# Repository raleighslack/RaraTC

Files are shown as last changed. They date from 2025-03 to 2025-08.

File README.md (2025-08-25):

# RSync Firmware  
The goal of this project is to create a system of devices that are able to wirelessly sync to each other and output SMPTE LTC Timecode to make editing effortless.

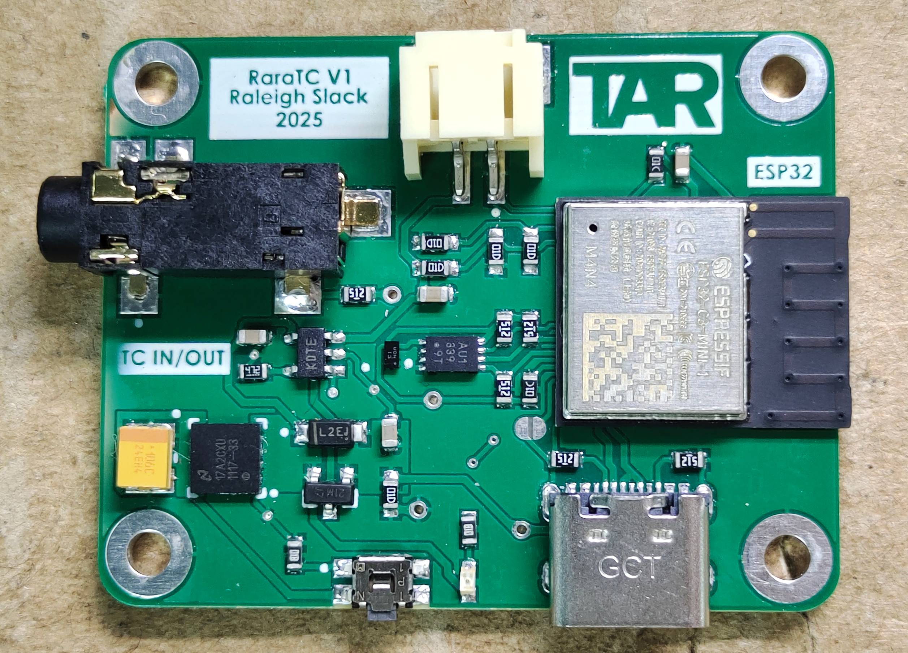
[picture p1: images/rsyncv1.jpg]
image info


## How to Use Example

### Hardware Required

The custom RSYNC board created by Raleigh Slack.  

### References used

[LTC Timecode Standard](https://law.resource.org/pub/in/bis/S04/is.12429.1.1988.pdf) - Describes the way in which LTC Timecode functions and gives specifications as how to meet the SMPTE standard.  
[USB-C in Embedded Designs: Practical Overview](https://fraimichael.medium.com/usb-c-in-embedded-designs-practical-overview-17bed72da05a) - A very good overview on how to incoporate USB-C into even the smallest designs.  
[ESP32-C3 Docs](https://docs.espressif.com/projects/esp-idf/en/v5.5/esp32c3/index.html) - Gives a great overview on how to use FreeRTOS, as well as ESP32 specific libraries.  

### Tools Used

[Altium Designer](https://www.altium.com/altium-designer) - Main PCB design software  
[EasyEDA](https://easyeda.com/) - Can generate footprints and symbols for Altium

### Build and Flash

Run `idf.py -p PORT flash monitor` to build, flash and monitor the project.

(To exit the serial monitor, type ``Ctrl-]``.)

See the [Getting Started Guide](https://docs.espressif.com/projects/esp-idf/en/latest/get-started/index.html) for full steps to configure and use ESP-IDF to build projects.

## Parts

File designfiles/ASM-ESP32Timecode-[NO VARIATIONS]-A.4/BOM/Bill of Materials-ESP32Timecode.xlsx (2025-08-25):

Line # | Name | Description | Designator | Revision ID | Revision Status | Quantity | Manufacturer 1 | Manufacturer Part Number 1 | Manufacturer Lifecycle 1 | Supplier 1 | Supplier Part Number 1 | Supplier Unit Price 1 | Supplier Subtotal 1
 | TAJB106M016RNJ | Tantalum Capacitor, 10 uF, +/- 20%, 16 V, -55 to 125 degC, 1411 (3528 Metric), RoHS, Tape and Reel | C1 | CMP-001-00050-7 | Up to date | 1 | Kyocera AVX | TAJB106M016RNJ | Volume Production | Future Electronics | 1399823 | 0.38 | 0.38
 | Capacitor 10µF +/-20% 10V 0603 | Chip Capacitor, 10µF +/-20%, 10V, 0603, Thickness 1 mm | C2, C3, C4, C5 | CMP-001-00075-4 | Up to date | 4 | Samsung | CL10A106KP8NNNC | Volume Production | Newark | 82AC9283 | 0.027 | 0.108
 | MBR120ESFT1G |  | D1 | CMP-1055-00434-2 | Up to date | 1 | ON Semiconductor | MBR120ESFT1G | Volume Production | Newark | 58M8776 | 0.134 | 0.134
 | VLMO1300-GS08 | VLMO1300-GS08 LED Uni-Color Soft Orange 611nm 2-Pin Chip 0603(1608Metric) T/R | D2 | CMP-00030-21709200-1 | Up to date | 1 | Vishay Semiconductors | VLMO1300-GS08 | Volume Production | Digikey | VLMO1300-GS08CT-ND | 0.22 | 0.22
 | USB4105-GF-A | CONN RCPT USB2.0 TYPEC 5A | J1 | CMP-245163-000001-1 | Up to date | 1 | Global Connector Technology | USB4105-GF-A | Unknown | Mouser | 640-USB4105-GF-A | 0.74 | 0.74
 | SJ2-35853B-SMT-TR | Connector | J2, J3 |  |  | 2
 | ESP32-C3-MINI-1-N4 | Multiprotocol Modules SMD module, ESP32-C3FN4, PCB antenna, -40 C +85 C | MD1 | CMP-10700-116589975-1 | Up to date | 1 | Espressif Systems | ESP32-C3-MINI-1-N4 | Unknown | Mouser | 356-ESP32-C3-MINI1N4 | 1.8 | 1.8
 | S2B-PH-K-S(LF)(SN) | Male Header, Pitch 2 mm, 1 x 2 Position, Height 4.8 mm, Tail Length 3.4 mm, -25 to 85 degC, RoHS, Bulk | P1 | CMP-1755-00004-1 | Up to date | 1 | JST | S2B-PH-K-S(LF)(SN) | Volume Production | Newark | 38K8066 | 0.037 | 0.037
 | DMG2301L-7 | MOSFET P-CH 20V 3A SOT23 | Q1 | CMP-12801-000065-1 | Up to date | 1 | Diodes | DMG2301L-7 | Volume Production | Digikey | DMG2301L-7DICT-ND | 0.23 | 0.23
 | AC0603FR-07100KL | RES 100KΩ 1.00% 0.1W 0603 | R1, R4, R5, R13, R14 | CMP-2000-04816-3 | Up to date | 5 | Yageo | AC0603FR-07100KL | Volume Production | Digikey | 311-100KLDCT-ND | 0.013 | 0.13
 | CRCW04021K00FKED | RES Thick Film, 1kΩ, 1%, 0.063W, 100ppm/°C, 0402 | R2, R8 | CMP-2002-08276-2 | Up to date | 2 | Vishay Dale | CRCW04021K00FKED | Volume Production | Avnet | 61M5261 | 0.012 | 0.12
 | CRCW04024K70FKED | RES Thick Film, 4.7kΩ, 1%, 0.063W, 100ppm/°C, 0402 | R3 | CMP-2002-00051-3 | Up to date | 1 | Vishay Dale | CRCW04024K70FKED | Unknown
 | CRCW06035K10FKEA | RES Thick Film, 5.1kΩ, 1%, 0.1W, 100ppm/°C, 0603 | R6, R7, R9, R10, R11, R12 | CMP-1012-00590-3 | Up to date | 6 | Bourns | CR0603-FX-5101ELF | Volume Production | Newark | 33AK8378 | 0.002 | 0.012
 | PTH-M2D5X5 | M2 PTH (2.5mm), 5mm pad | ST1, ST2, ST3, ST4 | CMP-00028-00004-2 | Up to date | 4
 | LM1117LD-3.3/NOPB | 800mA Low-Dropout Linear Regulator, 8-pin LLP, Pb-Free | U1 | CMP-0062-01399-3 | Up to date | 1 | TI National Semiconductor | LM1117LD-3.3/NOPB | Volume Production | Mouser | 926-LM1117LD33NOPB | 1.22 | 1.22
 | MCP7940MT-I/MNY | Low-Cost I2C™ Real-Time Clock / Calendar with SRAM, 400 KHz Communications Speed, 64 Bytes SRAM, -40 to 85 degC, 8-pin TDFN (MNY8), Tape and Reel | U2 | CMP-0186-00324-1 | Up to date | 1 | Microchip | MCP7940MT-I/MNY | Volume Production | Digikey | MCP7940MT-I/MNYCT-ND | 0.77 | 0.77
 | MCP73831T-2ACI/OT | IC CONTROLLR LI-ION 4.2V SOT23-5 | U3 | CMP-0133-00143-2 | Up to date | 1 | Microchip | MCP73831T-2ACI/OT | Volume Production | Farnell | 1332158 | 0.73832 | 0.73832
 | SIT1552AI-JF-DCC-32.768D | MEMS OSC TCXO 32.7680KHZ LVCMOS | Y1 | CMP-25159-262229-1 | Up to date | 1 | SiTime | SIT1552AI-JF-DCC-32.768D | Volume Production | Mouser | 788-1552AIJFDCC32.7D | 1.66 | 1.66

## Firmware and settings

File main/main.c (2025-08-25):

#include "freertos/FreeRTOS.h"
#include "freertos/task.h"
#include "esp_mac.h"
#include "esp_log.h"
#include "esp_timer.h"
#include "esp_wifi.h"
#include "esp_netif.h"
#include "esp_now.h"
#include "hal/cpu_hal.h"
#include "driver/gpio.h"
#include "smpte_timecode.h"
#include "communication.h"
#include "mcp7940.h"
#include "lipo.h"
#include "time.h"
#include "esp_sleep.h"
#include "nvs.h"
#include "mbedtls/base64.h"

#define USB_WAKE            0
#define LIPO_VOLTAGE        1
#define BTN_INPUT_PIN       3
#define LTC_OUTPUT_PIN      4
#define RTC_INPUT_PIN       5
#define LTC_FRAMERATE       24
#define LTC_BITS_PER_FRAME  80
#define CLOCK_TICKS_PER_SEC 160000000

#define GPIO_OUTPUT_PIN_SEL ((1ULL<<LTC_OUTPUT_PIN) | (1ULL<<LTC_OUTPUT_PIN))
#define GPIO_INPUT_RTC_PIN_SEL  ((1ULL<<RTC_INPUT_PIN) | (1ULL<<RTC_INPUT_PIN))
#define GPIO_INPUT_BTN_PIN_SEL  ((1ULL<<BTN_INPUT_PIN) | (1ULL<<BTN_INPUT_PIN))

static const char *TAG = "main";
static QueueHandle_t rtc_evt_queue;
static QueueHandle_t btn_evt_queue;

const float period_us = (((float)1/LTC_FRAMERATE)/LTC_BITS_PER_FRAME)*1000000;
const int64_t half_period_us = period_us/2.0;
const float frame_period_us = ((float)1/LTC_FRAMERATE) * 1000000;

volatile int frameOffset = 0;
volatile float timeOffsetMs = 1;
simple_frame current_simple_frame;
ltc_frame current_frame;
uint8_t current_bits[10];
esp_timer_handle_t periodic_timecode;
bool state = true;
volatile int bit_index = 0;                                                             //value from 0-79, the current transmitting bit
volatile int bit_local_counter = 0;                                                     //value either 0 or 1, either first half of period or 2nd half
static const char* BASE58_ALPHABET = "123456789ABCDEFGHJKLMNPQRSTUVWXYZabcdefghijkmnopqrstuvwxyz";

bool get_bit(uint8_t value, uint8_t index) {
    if (index > 7) return false;                                                        // Ensure index is within bounds
    return (value >> index) & 1;
}

static void lipo_task(void* arg) {
    while(1) {
        // float voltage = get_lipo_voltage();
        // ESP_LOGI(TAG, "VOLTAGE: %f", voltage);
        
        vTaskDelay(10000 / portTICK_PERIOD_MS);
    }
}

static void btn_task(void* arg) {
    int gpio_num;
    uint64_t prev_time = 0;
    bool is_down = false;
    while(1) {
        if (xQueueReceive(btn_evt_queue, &gpio_num, portMAX_DELAY)) {
            uint64_t current_time = esp_timer_get_time();
            uint64_t time_difference = current_time - prev_time;
            if (time_difference > 50000) {
                is_down = !is_down;
                float diff_helps = (float)(time_difference/1000000.0);
                ESP_LOGI(TAG, "BTN ISR, DIFFERENCE: %f, ISDOWN?: %d", diff_helps, is_down);
                prev_time = current_time;
                if((time_difference >= 5000000) && !is_down) {
                    ESP_ERROR_CHECK(ble_deinit());
                    vTaskDelete(xTaskGetHandle("lipo_task"));
                    esp_deep_sleep_start();
                }
            }
        }
    }
}

static void rtc_task(void* arg) {
    int gpio_num;
    while (1) {
        if (xQueueReceive(rtc_evt_queue, &gpio_num, portMAX_DELAY)) {
            if(gpio_num == RTC_INPUT_PIN) {
                uint64_t start = cpu_hal_get_cycle_count();
                uint8_t hours = get_rtc_hours();
                uint8_t minutes = get_rtc_minutes();
                uint8_t seconds = get_rtc_seconds();
                uint8_t days = get_rtc_date();

                int delayTime = (timeOffsetMs - ((cpu_hal_get_cycle_count() - start)/CLOCK_TICKS_PER_SEC) * 1000) / portTICK_PERIOD_MS;
                if(delayTime <0) {
                    delayTime=0;
                }

                vTaskDelay(delayTime);
                if (esp_timer_is_active(periodic_timecode)) {
                    ESP_ERROR_CHECK(esp_timer_stop(periodic_timecode));
                }

                current_simple_frame.frame = 0 + (frameOffset % LTC_FRAMERATE);
                current_simple_frame.second = seconds + (frameOffset / LTC_FRAMERATE);
                current_simple_frame.minute = minutes;
                current_simple_frame.hour = hours;

                if(current_simple_frame.second >= 60) {
                    current_simple_frame.minute += (current_simple_frame.second / 60);
                    current_simple_frame.second -= (60 - (current_simple_frame.second % 60));
                }

                // ESP_LOGI(TAG, "DAY: %d, TC ISR: %d:%d:%d:%d", days, current_simple_frame.hour, current_simple_frame.minute, current_simple_frame.second, current_simple_frame.frame);
        
                ESP_ERROR_CHECK(esp_timer_start_periodic(periodic_timecode, half_period_us));
            }
        }
    }
}

static void rtc_isr_handler(void* arg)
{
    int gpio_num = (int) arg;
    xQueueSendFromISR(rtc_evt_queue, &gpio_num, NULL);
}

static void btn_isr_handler(void* arg) {
    int gpio_num = (int) arg;
    xQueueSendFromISR(btn_evt_queue, &gpio_num, NULL);
}

void print_binary(uint8_t bits[10]) {
    for (int i = 0; i < 10; i++) {
        for (int j = 7; j >= 0; j--) {
            printf("%d", (bits[i] >> j) & 1);
        }
        printf(" ");
    }
    printf("\n");
}

void IRAM_ATTR periodic_timecode_callback(void* arg)
{
    bool bit = get_bit(reverse_bits(current_bits[(bit_index / 8)]), bit_index % 8);     //finally, a use for the modulo
    if(bit_local_counter == 0) {
        state = !state;
    }
    if(bit_local_counter == 1 && bit) {
        state = !state;
    }
    gpio_set_level(LTC_OUTPUT_PIN, state);
    bit_local_counter++;
    if(bit_local_counter >1) {
        bit_local_counter = 0;
        bit_index++;
    }
    if(bit_index > 79) {
        bit_index = 0;
        current_simple_frame.frame++;
        if(current_simple_frame.frame >= LTC_FRAMERATE) {
            current_simple_frame.frame = 0;
            current_simple_frame.second++;
            if(current_simple_frame.second >= 60) {
                current_simple_frame.second = 0;
                current_simple_frame.minute++;
                if(current_simple_frame.minute >= 60) {
                    current_simple_frame.minute = 0;
                    current_simple_frame.hour++;
                }
            }
        }
        create_frame_from_timecode(&current_frame, current_simple_frame.frame, current_simple_frame.second, current_simple_frame.minute, current_simple_frame.hour);
        create_bits_from_frame(current_bits, current_frame, LTC_FRAMERATE);
        // ESP_LOGI(TAG, "TC: %d:%d:%d:%d", current_simple_frame.hour, current_simple_frame.minute, current_simple_frame.second, current_simple_frame.frame);
        // log_frame_from_bits(current_bits);
        // print_binary(current_bits);
    }
}

void encode_base58(uint64_t value, char *output, size_t output_size) {
    char buffer[16]; // max 11 chars for 64-bit + null
    int i = 0;

    do {
        buffer[i++] = BASE58_ALPHABET[value % 58];
        value /= 58;
    } while (value && i < (int)(sizeof(buffer) - 1));

    buffer[i] = '\0';

    // Reverse the string into output
    for (int j = 0; j < i; ++j) {
        output[j] = buffer[i - j - 1];
    }
    output[i] = '\0';
}

void app_main(void)
{
    gpio_config_t io_conf = {};
    io_conf.intr_type = GPIO_INTR_DISABLE;
    io_conf.mode = GPIO_MODE_OUTPUT;
    io_conf.pin_bit_mask = GPIO_OUTPUT_PIN_SEL;
    // gpio_config(&io_conf);

    io_conf.intr_type = GPIO_INTR_POSEDGE;
    io_conf.mode = GPIO_MODE_INPUT;
    io_conf.pin_bit_mask = GPIO_INPUT_RTC_PIN_SEL;
    io_conf.pull_up_en = false;
    io_conf.pull_down_en = false;
    gpio_config(&io_conf);

    io_conf.intr_type = GPIO_INTR_ANYEDGE;
    io_conf.pin_bit_mask = GPIO_INPUT_BTN_PIN_SEL;
    gpio_config(&io_conf);
    
    ESP_ERROR_CHECK(init_rtc());
    ESP_ERROR_CHECK(init_lipo());
    ESP_ERROR_CHECK(nvs_rara_init());

    current_simple_frame.hour = get_rtc_hours();
    current_simple_frame.minute = get_rtc_minutes();

    const esp_timer_create_args_t periodic_timecode_args = {
        .callback = &periodic_timecode_callback,
        /* name is optional, but may help identify the timer when debugging */
        .name = "periodic_timecode"
    };
    // ESP_ERROR_CHECK(esp_timer_create(&periodic_timecode_args, &periodic_timecode));

    ESP_ERROR_CHECK(gpio_install_isr_service(ESP_INTR_FLAG_LEVEL1));
    ESP_ERROR_CHECK(esp_deep_sleep_enable_gpio_wakeup(BIT(BTN_INPUT_PIN), ESP_GPIO_WAKEUP_GPIO_HIGH));
    // ESP_ERROR_CHECK(gpio_isr_handler_add(RTC_INPUT_PIN, rtc_isr_handler, (void*) RTC_INPUT_PIN));
    ESP_ERROR_CHECK(gpio_isr_handler_add(BTN_INPUT_PIN, btn_isr_handler, (void*) BTN_INPUT_PIN));

    rtc_evt_queue = xQueueCreate(10, sizeof(int));
    xTaskCreate(rtc_task, "rtc_task", 2048, NULL, 10, NULL);

    btn_evt_queue = xQueueCreate(10, sizeof(int));
    xTaskCreate(btn_task, "btn_task", 2048, NULL, 10, NULL);
    xTaskCreate(lipo_task, "lipo_task", 2048, NULL, 10, NULL);

    if((get_rtc_register(REG_SECONDS) | 127) != 0xFF) {
        ESP_ERROR_CHECK(set_rtc_register(REG_CONTROL, 0x48));                           //sets 1hz square wave output, and external clock input in the rtc
        ESP_ERROR_CHECK(set_rtc_register(REG_SECONDS, 0x80));                           //tells the rtc to actually start keeping time
    }

    uint64_t serial_number = get_serial_no();
    ESP_LOGI(TAG, "%" PRId64 "\n", serial_number);
    char serial_base58[16];  // Plenty of room (max 11 chars + null)
    encode_base58(serial_number, serial_base58, sizeof(serial_base58));

    char bt_name[32];
    snprintf(bt_name, sizeof(bt_name), "RSYNC - %s", serial_base58);
    bluetooth_main(bt_name);

    uint8_t testbits[10];
    ltc_frame testframe;
    testframe.drop_frame_flag = false;
    testframe.frame = 16;
    testframe.second = 23;
    testframe.minute = 33;
    testframe.hour = 9;
    create_bits_from_frame(testbits, testframe, 24);
    print_binary(testbits);
}

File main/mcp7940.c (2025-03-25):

#include "mcp7940.h"

i2c_master_bus_handle_t bus_handle;
i2c_master_dev_handle_t dev_handle;

static esp_err_t i2c_get_port(int port, i2c_port_t *i2c_port) {
    if (port >= I2C_NUM_MAX) {
        return ESP_FAIL;
    }
    *i2c_port = port;
    return ESP_OK;
}

esp_err_t init_rtc(void) {
    i2c_port_t port;
    ESP_ERROR_CHECK(i2c_get_port(0, &port));
    i2c_master_bus_config_t i2c_mst_config = {
        .clk_source = I2C_CLK_SRC_DEFAULT,
        .i2c_port = port,
        .scl_io_num = SCL_PIN,
        .sda_io_num = SDA_PIN,
        .glitch_ignore_cnt = 7,
        .flags.enable_internal_pullup = false,
    };
    
    ESP_ERROR_CHECK(i2c_new_master_bus(&i2c_mst_config, &bus_handle));
    
    i2c_device_config_t dev_cfg = {
        .dev_addr_length = I2C_ADDR_BIT_LEN_7,
        .device_address = MCP7940_I2C,
        .scl_speed_hz = 400000,
    };
    
    return i2c_master_bus_add_device(bus_handle, &dev_cfg, &dev_handle);
}

uint8_t get_rtc_seconds() {
    uint8_t data;
    uint8_t register_sec = REG_SECONDS;
    i2c_master_transmit_receive(dev_handle, &register_sec, 1, &data, 1, -1);
    uint8_t tens = (data >> 4) & 0b0111;                                            // Extract bits 6-4
    uint8_t ones = data & 0b1111;                                                   // Extract bits 3-0
    return (tens * 10) + ones;
}

uint8_t get_rtc_minutes() {
    uint8_t data;
    uint8_t register_sec = REG_MINUTES;
    i2c_master_transmit_receive(dev_handle, &register_sec, 1, &data, 1, -1);
    uint8_t tens = (data >> 4) & 0b0111;                                            // Extract bits 6-4
    uint8_t ones = data & 0b1111;                                                   // Extract bits 3-0
    return (tens * 10) + ones;
}

uint8_t get_rtc_hours() {
    uint8_t data;
    uint8_t register_sec = REG_HOUR;
    i2c_master_transmit_receive(dev_handle, &register_sec, 1, &data, 1, -1);
    bool isTwelveHourMode = (data & 0b01000000) != 0;
    uint8_t tens;
    if(!isTwelveHourMode) {
        tens = (data >> 4) & 0b0011;
    } else {
        tens = (data >> 4) & 0b0001;
    }
    uint8_t ones = data & 0b1111;                                                   // Extract bits 3-0
    return (tens * 10) + ones;
}

uint8_t get_rtc_weekday() {
    uint8_t data;
    uint8_t register_sec = REG_WEEKDAY;
    i2c_master_transmit_receive(dev_handle, &register_sec, 1, &data, 1, -1);
    uint8_t ones = data & 0b0111;                                                   // Extract bits 2-0
    return ones;
}

uint8_t get_rtc_date() {
    uint8_t data;
    uint8_t register_sec = REG_DATE;
    i2c_master_transmit_receive(dev_handle, &register_sec, 1, &data, 1, -1);
    uint8_t tens = (data >> 4) & 0b0011;                                            // Extract bits 6-4
    uint8_t ones = data & 0b1111;                                                   // Extract bits 3-0
    return (tens * 10) + ones;
}

uint8_t get_rtc_month() {
    uint8_t data;
    uint8_t register_sec = REG_MONTH;
    i2c_master_transmit_receive(dev_handle, &register_sec, 1, &data, 1, -1);
    uint8_t tens = (data >> 4) & 0b0001;                                            // Extract bits 6-4
    uint8_t ones = data & 0b1111;                                                   // Extract bits 3-0
    return (tens * 10) + ones;
}

uint8_t get_rtc_year() {
    uint8_t data;
    uint8_t register_sec = REG_YEAR;
    i2c_master_transmit_receive(dev_handle, &register_sec, 1, &data, 1, -1);
    uint8_t tens = (data >> 4) & 0b1111;                                            // Extract bits 6-4
    uint8_t ones = data & 0b1111;                                                   // Extract bits 3-0
    return (tens * 10) + ones;
}

esp_err_t set_rtc_seconds(uint8_t seconds) {
    uint8_t tens = (seconds / 10) & 0b0111;                                         // Extract tens place and mask
    uint8_t ones = (seconds % 10) & 0b1111;                                         // Extract ones place and mask
    uint8_t encoded = (1 << 7) | (tens << 4) | ones;                                // Set flag bit, shift tens, and add ones
    uint8_t write_buf[2] = {REG_SECONDS, encoded};
    return i2c_master_transmit(dev_handle, write_buf, sizeof(write_buf), -1);
}

esp_err_t set_rtc_minutes(uint8_t minutes) {
    uint8_t tens = (minutes / 10) & 0b0111;
    uint8_t ones = (minutes % 10) & 0b1111;
    uint8_t encoded = ((tens << 4) | ones);
    uint8_t write_buf[2] = {REG_MINUTES, encoded};
    return i2c_master_transmit(dev_handle, write_buf, sizeof(write_buf), -1);
}

esp_err_t set_rtc_hour_mode24(uint8_t hour) {
    uint8_t tens = (hour / 10) & 0b0011;
    uint8_t ones = (hour % 10) & 0b1111;
    uint8_t encoded = (HOUR_MODE_24 << 6) | (tens << 4) | ones;
    uint8_t buffer[2] = {REG_HOUR, encoded};
    return i2c_master_transmit(dev_handle, buffer, sizeof(buffer), -1);
}

esp_err_t set_rtc_weekday(uint8_t weekday) {
    uint8_t weekdayencoded = weekday & 0b0111;
    uint8_t weekdaybuffer[2] = {REG_WEEKDAY, weekdayencoded};
    return i2c_master_transmit(dev_handle, weekdaybuffer, sizeof(weekdaybuffer), -1);
}

esp_err_t set_rtc_date(uint8_t date) {
    uint8_t datetens = (date / 10) & 0b0011;
    uint8_t dateones = (date % 10) & 0b1111;
    uint8_t dateencoded = (datetens << 4) | dateones;
    uint8_t datebuffer[2] = {REG_DATE, dateencoded};
    return i2c_master_transmit(dev_handle, datebuffer, sizeof(datebuffer), -1);
}

esp_err_t set_rtc_month(uint8_t month, uint8_t year) {
    uint8_t monthtens = (month / 10) & 0b0001;
    uint8_t monthones = (month % 10) & 0b1111;
    bool isLeapYear = (year%4==0) ? true : false;
    uint8_t monthencoded = (isLeapYear << 6) | (monthtens << 4) | monthones;
    uint8_t monthbuffer[2] = {REG_MONTH, monthencoded};
    return i2c_master_transmit(dev_handle, monthbuffer, sizeof(monthbuffer), -1);
}

esp_err_t set_rtc_year(uint8_t year) {
    uint8_t yeartens = (year / 10) & 0b1111;
    uint8_t yearones = (year % 10) & 0b1111;
    uint8_t yearencoded = ((yeartens << 4) | yearones);
    uint8_t yearbuffer[2] = {REG_YEAR, yearencoded};
    return i2c_master_transmit(dev_handle, yearbuffer, sizeof(yearbuffer), -1);
}

esp_err_t set_rtc_date_from_bt(uint8_t year, uint8_t month, uint8_t date, uint8_t weekday, uint8_t hour, uint8_t minute, uint8_t second) {
    set_rtc_register(REG_SECONDS, 0x00);//Stops the rtc from counting.
    set_rtc_register(REG_CONTROL, 0x00);//Stops the rtc from counting using the external oscillator. 
    esp_err_t status = ESP_OK;

    status += set_rtc_year(year);
    status += set_rtc_month(month, year);
    status += set_rtc_date(date);
    status += set_rtc_weekday(weekday);
    status += set_rtc_hour_mode24(hour);
    status += set_rtc_minutes(minute);
    status += set_rtc_register(REG_CONTROL, 0x48);
    status += set_rtc_seconds(second);
    
    return status;
}
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

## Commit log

2025-02-05 Completed most of create bits from frame
    i shorted my dev board and it brokey :(
    [main.c]
2025-02-05 Added timer period test for timecode
2025-02-10 Still cant get end frame right
2025-02-11 Fix timing + me being dumb
    [main.c]
2025-02-12 IT WORKS
    The bits were reversed, now the timecode gets legit recognized in davinci resolve
    [main.c]
2025-03-18 THE BOARDS WORK+ i2c scan task
2025-03-19 Working i2c but jank
2025-03-20 Finished all getters, started 1hz intr
2025-03-20 stack overflow👽
2025-03-21 Fixed crashing (read disc)
    Turns out its bad to call any kind of non-isr functions inside of a callback. (Who would have thought?) This includes logging functions like ESP_LOGI() or printf(). So that is what was crashing it. Instead I implemented an XQueue, and now it works!
    [main.c, mcp7940.c]
2025-03-21 Time based on interrupt
2025-03-22 Need to make a fix (read disc)
    So you cant actually change the sub-second timing of the rtc to match with other rtc's. SO i'm going to have to go and make some kind of frame offset that can be calculated to sync units to the frame.
    [main.c, mcp7940.c]
2025-03-22 Added offset (read disc)
    Maybe I should switch the isr to 4khz instead of 1hz, that way I can use the frame offset with decimals to offset the triggering of the main irq
2025-03-23 fixed bug + wifi
    [main.c]
2025-03-25 Add in ESP_NOW and fix bug
    Bug is where the 12/24 hours recieve are switched. Fixed now.
    [main.c, mcp7940.c]
2025-07-08 parted out isr handlers
    also the adc cant read more than 3.3v sooooo
2025-07-08 Added button toggled sleep!
2025-07-08 Put battery check in its own task
2025-07-10 added seperate lipo
    also added lipo voltage to bluetooth
2025-08-04 add battery percentage
2025-08-25 Added design + v1 pcb files
    [Bill of Materials-ESP32Timecode.xlsx, ESP32Timecode.PrjPcb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]
